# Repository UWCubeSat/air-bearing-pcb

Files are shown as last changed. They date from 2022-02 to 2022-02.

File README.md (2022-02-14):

# [PCB for the Air Bearing](https://online.huskysatellitelab.com/wiki/index.php/2021_Intro_Projects#Design_PCB_for_the_Air_Bearing)

As the project developed over the course of the summer, our air bearing test stand's electrical system needed to be quickly assembled onto a perfboard Arduino shield. Now that we have time, we'd like to replace that janky jury-rigged board with a PCB to make the system more robust and reduce the number of loose wires holding the electronics together. Currently, the circuit is responsible for connecting the I2C lines of the Arduino Uno to several sensors and an external system through a logic level shifter, communicating with a Bluetooth module over UART, receiving power from a battery, and providing reset functionality in software.

**Point of Contact:** Sebastian Soetomo or Andrew Buckingham

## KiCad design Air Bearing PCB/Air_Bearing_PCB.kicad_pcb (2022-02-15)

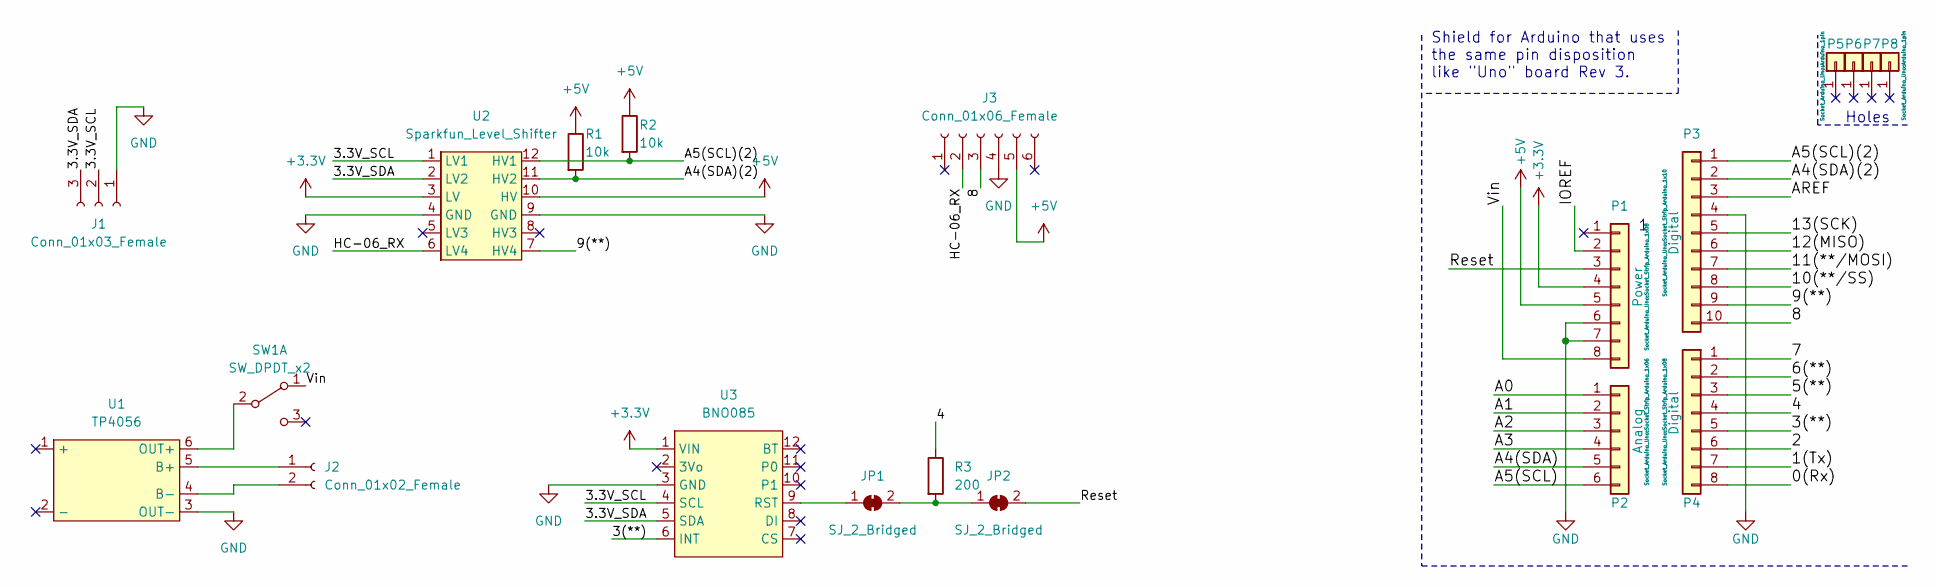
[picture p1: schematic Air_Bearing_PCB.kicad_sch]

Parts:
J1: Conn_01x03_Female; PinSocket_1x03_P2.54mm_Vertical
J2: Conn_01x02_Female; PinSocket_1x02_P2.54mm_Vertical
J3: Conn_01x06_Female; PinSocket_1x06_P2.54mm_Vertical
JP1, JP2: SJ_2_Bridged; SolderJumper-2_P1.3mm_Open_RoundedPad1.0x1.5mm
P1: Power; Socket_Strip_Arduino_1x08
P2: Analog; Socket_Strip_Arduino_1x06
P3: Digital; Socket_Strip_Arduino_1x10
P4: Digital; Socket_Strip_Arduino_1x08
P5, P6, P7, P8: CONN_01X01; Arduino_1pin
R1, R2: 10k; R_0603_1608Metric_Pad0.98x0.95mm_HandSolder
R3: 200; R_0603_1608Metric_Pad0.98x0.95mm_HandSolder
SW1: SW_DPDT_x2; PinHeader_1x03_P2.54mm_Vertical
U1: TP4056
U2: Sparkfun_Level_Shifter; Level_Shifter
U3: BNO085

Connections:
+3V3: P1.4, U2.3 (LV), U3.1 (VIN)
+5V: J3.5, P1.5, R1.1, R2.1, U2.10 (HV)
/0(Rx): P4.8
/1(Tx): P4.7
/2: P4.6
/3(**): P4.5, U3.6 (INT)
/3.3V_SCL: J1.2, U2.1 (LV1), U3.4 (SCL)
/3.3V_SDA: J1.3, U2.2 (LV2), U3.5 (SDA)
/4: P4.4, R3.1
/5(**): P4.3
/6(**): P4.2
/7: P4.1
/8: J3.3, P3.10
/9(**): P3.9, U2.7 (HV4)
/10(**/SS): P3.8
/11(**/MOSI): P3.7
/12(MISO): P3.6
/13(SCK): P3.5
/A0: P2.1
/A1: P2.2
/A2: P2.3
/A3: P2.4
/A4(SDA): P2.5
/A4(SDA)(2): P3.2, R1.2, U2.11 (HV2)
/A5(SCL): P2.6
/A5(SCL)(2): P3.1, R2.2, U2.12 (HV1)
/AREF: P3.3
/HC-06_RX: J3.2, U2.6 (LV4)
/IOREF: P1.2
/Reset: JP2.2 (B), P1.3
/Vin: P1.8, SW1.1 (A)
GND: J1.1, J3.4, P1.6, P1.7, P3.4, U1.3 (OUT-), U2.4 (GND), U2.9 (GND), U3.3 (GND)
unnamed: J2.1, U1.5 (B+)
unnamed: J2.2, U1.4 (B-)
unnamed: JP1.1 (A), U3.9 (RST)
unnamed: JP1.2 (B), JP2.1 (A), R3.2
unnamed: SW1.2 (B), U1.6 (OUT+)

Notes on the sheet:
Holes
Shield for Arduino that uses the same pin disposition like "Uno" board Rev 3.

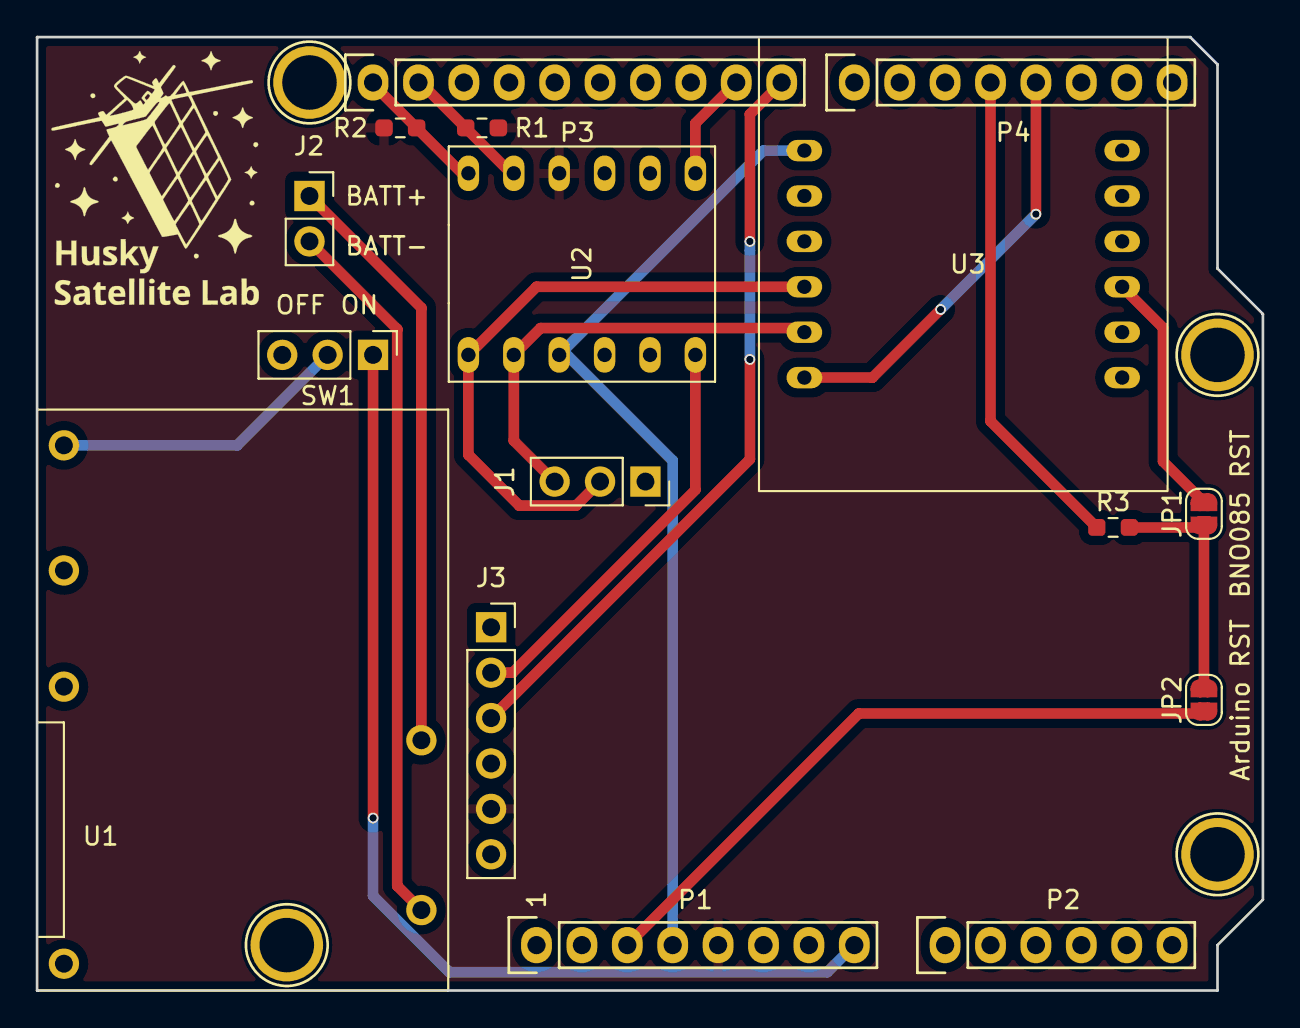
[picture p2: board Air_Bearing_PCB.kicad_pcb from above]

Board: 2 copper layers, 68.6 x 53.3 mm, 20 parts (0 on the bottom side), 19 nets.

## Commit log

2022-02-14 Added preliminary PCB
    Added preliminary PCB and updated README
    [Air_Bearing_PCB.kicad_pcb, Air_Bearing_PCB.kicad_sch]
2022-02-15 Added Gerber Files
    Made a few small routing and schematic edits. Added Gerber files.
    [Air_Bearing_PCB-B_Cu.gbl, Air_Bearing_PCB-B_Mask.gbs, Air_Bearing_PCB-B_Paste.gbp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]
